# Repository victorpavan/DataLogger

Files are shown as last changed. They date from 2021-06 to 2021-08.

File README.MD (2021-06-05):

# ARDUINO DATA LOGGER 

Sistema de coleta de dados de temperatura e umidade.

O sistema utiliza um módulo de controle para 3 módulos de sensores, cada controlador gravando os dados em um cartão micro-SD em intervalos predeterminados.

Os módulos de controle utilizam um Arduino UNO como controlador principal, sendo o master dos barramentos I2C de cada bloco de sensores.

## Componentes

Para os módulos de controle, foram utilizados:

 * 1 - [Arduino UNO REV3](https://www.eletrogate.com/uno-r3-cabo-usb-para-arduino)
 * 1 - [Módulo RTC DS1307](https://www.eletrogate.com/modulo-real-time-clock-ds1307)
 * 1 - [Módulo SD Card Reader](https://www.eletrogate.com/modulo-micro-sd-card)

Para os módulos de sensores, foram utilizados:

 * 1 - [Sensor de Temperatura e Umidade HDC1080](https://www.eletrogate.com/modulo-gy-213-sensor-de-temperatura-e-umidade-hdc1080)
 * 1 - [Sensor de Temperatura IR MLX90614](https://www.filipeflop.com/produto/sensor-de-temperatura-ir-mlx90614/)
 * 1 - [Sensor de Som KY-038](https://www.eletrogate.com/modulo-sensor-de-som)

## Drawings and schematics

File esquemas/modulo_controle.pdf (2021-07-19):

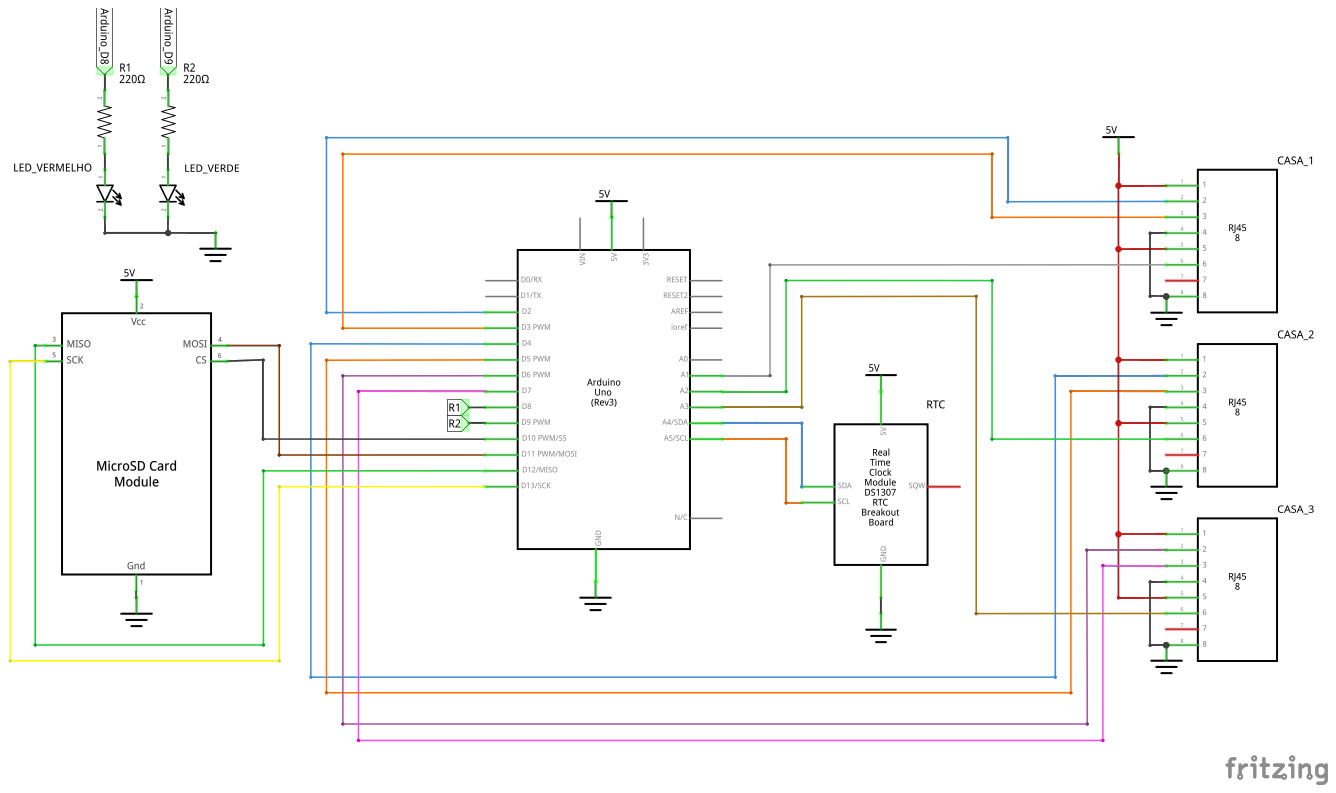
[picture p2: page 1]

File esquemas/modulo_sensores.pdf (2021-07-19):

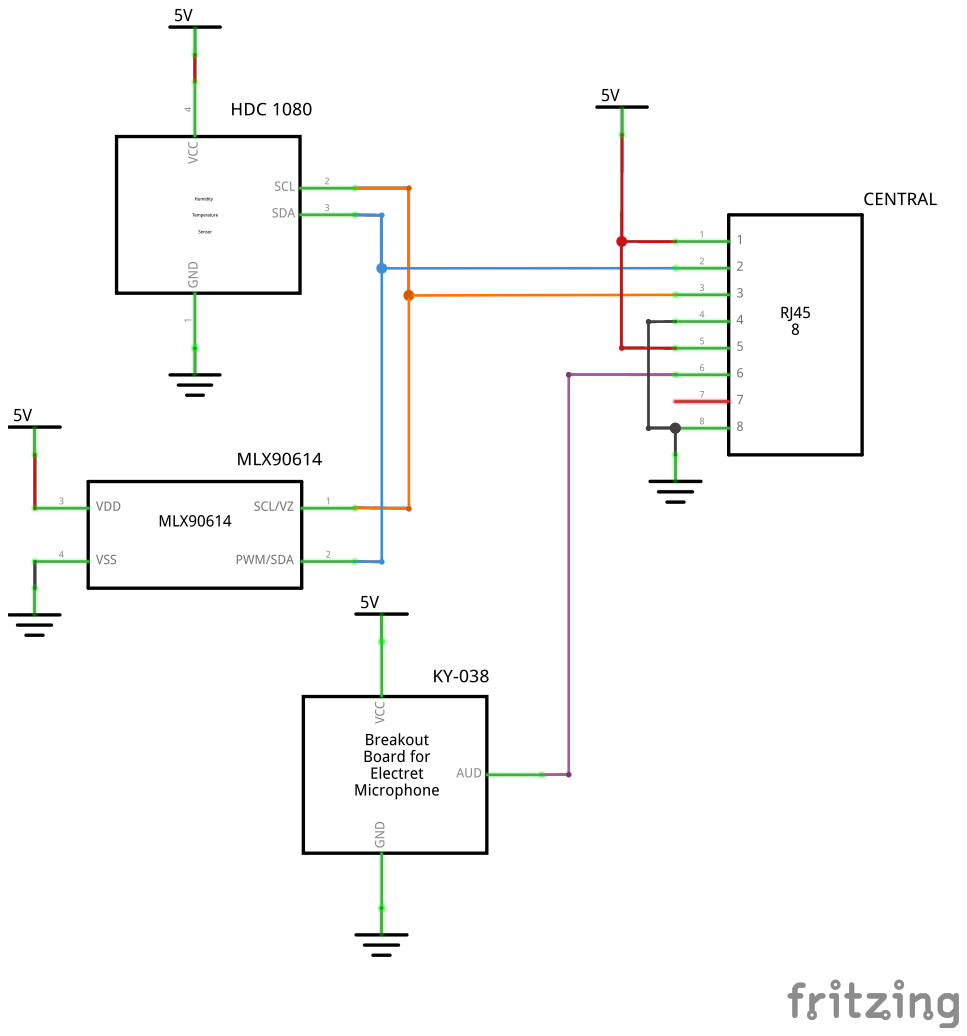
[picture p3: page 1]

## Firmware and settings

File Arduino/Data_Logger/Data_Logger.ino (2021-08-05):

//DATALOGGER ARDUINO

#include<ClosedCube_HDC1080.h>
#include<Adafruit_MLX90614.h>
#include<TimeLib.h>
#include<Wire.h>
#include<DS1307RTC.h>
#include<SPI.h>
#include<SdFat.h>

//Configurações gerais (alterar de acordo com a necessidade)

#define SERIALBAUD 9600
#define action_r 8
#define action_g 9
#define n_amostras 2000
#define periodo_aquisicao 10 //minutos

//Definicoes de variáveis globais
unsigned int relogio[6]; //{hora, minuto, segundo, dia, mes, ano}
#define CS 10
bool pronto = false;
bool cartao_ok = true;
bool cartao_ok_led = false;

//Definição dos barramentos I2C
//SoftwareWire(sda, slc);
SoftwareWire barramento[] = {SoftwareWire(2,3), SoftwareWire(4,5), SoftwareWire(6,7)};

//Definição dos objetos dos sensores de temperatura(hdc) e infravermelho(mlx)
ClosedCube_HDC1080 hdc[3];
Adafruit_MLX90614 mlx[3];

//Inicializacao das variavel de intensidade sonora
int intensidade_som[3] = {0,0,0};

int amostraSom(int pinoAnalogico, int variavel){

	int maior = 0;
	int menor = 1024;


	for(unsigned int i=0; i<n_amostras; i++){

		int valor = analogRead(pinoAnalogico);

		if(valor>maior){
			maior = valor;
		}

		if(valor<menor){
			menor = valor;
		}
	}
		

	int resultado = (maior - menor)/2;

	if(resultado>variavel){
		return resultado;
	}else{
		return variavel;
	}
}


void blink(byte code){
	while(1){
		digitalWrite(action_g, LOW);
		digitalWrite(action_r, bitRead(code, 0));
		delay(200);
		digitalWrite(action_r, LOW);
		delay(200);

		digitalWrite(action_r, bitRead(code, 1));
		delay(200);
		digitalWrite(action_r, LOW);
		delay(200);

		digitalWrite(action_r, bitRead(code, 2));
		delay(200);
		digitalWrite(action_r, LOW);
		delay(200);

		digitalWrite(action_r, bitRead(code, 3));
		delay(200);
		digitalWrite(action_r, LOW);
		delay(200);

		delay(1000);
	}
}


void timestep() {

	tmElements_t tm;

	if(RTC.read(tm)){

		relogio[0] = tm.Hour;
        relogio[1] = tm.Minute;
		relogio[2] = tm.Second;
		relogio[3] = tm.Day;
		relogio[4] = tm.Month;
		relogio[5] = tmYearToCalendar(tm.Year);

	}else{

		if (RTC.chipPresent()) {
			//Acertar Relogio
			blink(0b11);
		}else{
			//Problema com o modulo
			blink(0b1111);
		}
	}
}

void setup(){

	//Inicialização da comunicação serial
	Serial.begin(SERIALBAUD);
	//log(String("Inicializando comunicação serial a " + SERIALBAUD))

	//Inicializacao dos leds
	pinMode(action_r, OUTPUT);
	pinMode(action_g, OUTPUT);

	//Inicializacao dos sensores nos barramentos I2C
	for(int i=0; i < 3; i++){
		hdc[i].begin(0x40, barramento[i]);
		mlx[i].begin(barramento[i]);
	}

	//Teste do cartao
	setupSdcard();
	//Tudo certo para comecar
	digitalWrite(action_g, HIGH);

	
	//Cria cabecalho para marcar inicializacao
	if(cartao_ok){
		salvar("4", true);
		delay(100);
		salvar("5", true);
		delay(100);
		salvar("6", true);
	}

}

void loop(){

	for(int i=0; i < 3; i++){
		if(hdc[i].readTemperature() < 124.00){
			Serial.print(i+1);
			Serial.print(';');
			Serial.print(hdc[i].readTemperature());
			Serial.print(';');
			Serial.print(hdc[i].readHumidity());
			Serial.print(';');
			Serial.print(mlx[i].readObjectTempC());
			Serial.print(';');
			Serial.println(intensidade_som[i]);
		}else{
			Serial.print(i+1);
			Serial.print(';');
			Serial.print("N/A");
			Serial.print(';');
			Serial.print("N/A");
			Serial.print(';');
			Serial.print("N/A");
			Serial.print(';');
			Serial.println("N/A");
		}
	}


	intensidade_som[0] = amostraSom(A0, intensidade_som[0]);
	intensidade_som[1] = amostraSom(A1, intensidade_som[1]);
	intensidade_som[2] = amostraSom(A2, intensidade_som[2]);

	timestep();
	if(!cartao_ok){
	   	digitalWrite(action_g, cartao_ok_led);
		cartao_ok_led = !cartao_ok_led;
	}else{
		if(relogio[1]%periodo_aquisicao == 0){
			if(!pronto){
				salvar("4", false);
				delay(100);
				salvar("5", false);
				delay(100);
				salvar("6", false);
				pronto = true;
			}
		}else{
			pronto = false;
		}
	}
	delay(200);
}

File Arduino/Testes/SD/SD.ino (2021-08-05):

#include<SPI.h>
#include<SdFat.h>:

SdFat sdCard;
SdFile arquivo;

#define CS 10

void salvar(char *casa){

	int numerocasa = casa[0]-'0';

	Serial.println(numerocasa+5);

	if(!sdCard.begin(CS,SPI_HALF_SPEED)){
		digitalWrite(8, 1);
		sdCard.initErrorHalt();
	}

	if (!arquivo.open(casa, O_RDWR | O_CREAT | O_AT_END)){
		delay(300);
		digitalWrite(8, LOW);
		delay(500);
		digitalWrite(8, HIGH);
	}else{
		arquivo.println("Comunicacao com SD funcional");
	}

	arquivo.close();
	delay(1000);

}
void setup(){
	Serial.begin(9600);
	pinMode(8, OUTPUT);
	salvar("5");
}

void loop(){
}

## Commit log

2021-06-05 Arquivos Atualizados
    [modulo_controle.fzz, modulo_sensores.fzz]
2021-07-12 Esquemas Atualizados no formato PDF para melhor leitura
2021-07-12 Funcao do gravacao de dados agora recebe um caractere como parametro
2021-07-19 Adicionado Novo LED de indicacao
    Adicionado modo de monitoramento USB
    Adicionado erro de verificacao de cartao
    Agora quando reiniciado, cria novo cabecalho no arquivo
2021-07-19 Esquemas atualizados com LED verde e linha analogica para pino 6
    [modulo_controle.fzz, modulo_sensores.fzz]
2021-07-22 Adicionada funcao para amostragem de som
2021-08-05 Adicionada pasta de testes
